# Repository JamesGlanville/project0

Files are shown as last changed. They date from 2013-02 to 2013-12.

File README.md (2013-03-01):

project0
========

My simple code for a launchpad VFD clock. Read the code for details, but the basic idea is:

On first power-up, the time is read via i2c from a DS1307 RTC chip.
One input is connected to the square wave 1Hz output of the DS1307, and increments the second counter on an interrupt.
One output is PWM'ed to drive a switch mode power supply that boosts 5v-50V for the tubes.
Three outputs send data to the MAX6921 driver chip constantly to keep the persistence of vision effect working.

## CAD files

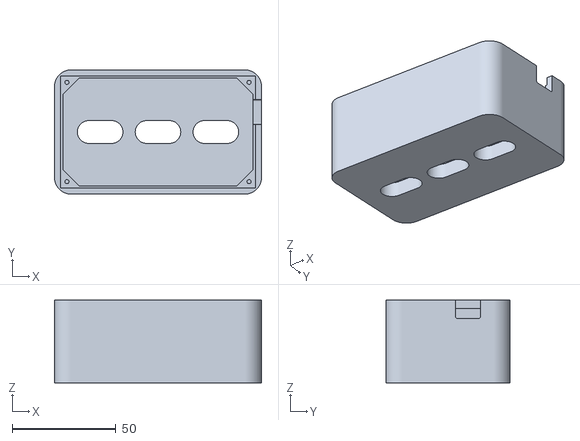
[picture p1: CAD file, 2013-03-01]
tube clock_fixed.stl
100.0 x 60.0 x 40.0

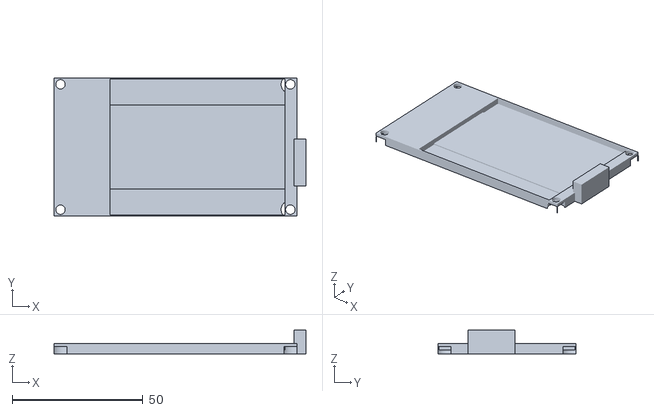
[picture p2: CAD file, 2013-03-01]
baselid.stl
96.5 x 53.0 x 9.00

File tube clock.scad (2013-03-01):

length=100;
width=60;
height=40;//35
cornerrad=8;
tubedia=11;
tubeseparation=27.94;//distance between center of tube clusters.
wallthickness=4;
screwx=length/2-1.5*wallthickness;
screwy=width/2-1.5*wallthickness;
screwrad=1;
lpy=52;
lpx=67;
//cube(24);
//88   52           30

$fn=100;

use <MCAD/boxes.scad>
use <MCAD/triangles.scad>
module body(){
mirror([0,0,1]){
difference()
{
translate([0,0,height/2])roundedBox([length,width,height],cornerrad,true);

difference(){
translate([0,0,height/2-7.5])roundedBox([length-wallthickness*2,width-wallthickness*2,height],0,true);

for (a=[1,-1]){
for (b=[1,-1]){
translate([a*length/1.6,b*width/2,height/2-wallthickness])rotate([0,0,45])cube(height,center=true);

}}}

for (c=[-1:1]){
translate([c*tubeseparation,0,0])roundedBox([tubedia*2,tubedia,100],tubedia/2,true);}


//roundedBox([length-wallthickness*1.5,width-wallthickness*1.5,1],0,true);
for (d=[1,-1]){
for (e=[1,-1]){
translate([d*screwx,e*screwy,-1])cylinder(r=screwrad,h=height-5);
}}
cube([length-wallthickness*1.5,width-1.5*wallthickness,wallthickness*2],center=true);
translate([50,9.68,2.49])roundedBox([100,12,13],1,false);
//cube([200,3,9]);
}}}

//translate([0,50,0]){
mirror([0,0,1])
difference(){

union(){
cube([length-wallthickness*1.5-1,width-1.5*wallthickness-1,wallthickness],center=true);
translate([length/2-wallthickness*0.75-1.5,-30/2,-7])cube([4.5,18,9]);



}
translate([-25,-lpy/2,-4])cube([lpx,lpy,4]);
translate([-25,-lpy/2,-3.5])cube([lpx,10,4]);
mirror([0,1,0])translate([-25,-lpy/2,-3.5])cube([lpx,10,4]);
/*translate([0,0,0.2])cylinder(r=10.5,h=10);
translate([27,0,0.2])cylinder(r=10.5,h=10);
translate([-27,0,0.2])cylinder(r=10.5,h=10);
translate([13.5,16,0.2])cylinder(r=10.5,h=10);
translate([13.5,-16,0.2])cylinder(r=10.5,h=10);
translate([-13.5,16,0.2])cylinder(r=10.5,h=10);
translate([-13.5,-16,0.2])cylinder(r=10.5,h=10);*/
for (d=[1,-1]){
for (e=[1,-1]){
translate([d*screwx,e*screwy,-5])cylinder(r=1.8,h=height-5);
translate([d*screwx,e*screwy,-0.7])cylinder(r=3.53,h=height-5);
}}
}

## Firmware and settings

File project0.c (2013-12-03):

#include "inc/hw_types.h"
#include "inc/hw_memmap.h"
#include "inc/hw_ints.h"
#include "inc/hw_gpio.h"
#include "inc/hw_timer.h"
#include "driverlib/sysctl.h"
#include "driverlib/gpio.h"
#include "driverlib/interrupt.h"
#include "driverlib/pwm.h"
#include "driverlib/timer.h"
#include "driverlib/pin_map.h"
#include "inc/lm4f120h5qr.h"
#include <stdint.h>
#include "softPwm.h" //From here: https://github.com/arcadien/pwm_test_stellpad1/tree/master/lab_project
#include "I2C_Stellaris_API.h" //From here: http://e2e.ti.com/support/microcontrollers/stellaris_arm/f/471/t/235926.aspx

#define DIN GPIO_PIN_1	//These are all on port F.
#define CLK GPIO_PIN_2	//They correspond to the 3 control wires going to the MAX6921.
#define LOAD GPIO_PIN_3

#define SECONDPULSE GPIO_PIN_6	//Port C. SECONDPULSE is connected to the 1Hz SQW output of the ds1307
#define SMPS_PWM GPIO_PIN_2		//Port B. This pin is connected to the SMPS mosfet gate for switching.

#define dutyCycle 40	//This is trial and error open-loop control - hacky but works well.
#define DS1307ADDRESS 0x68 //The i2c slave address of the DS1307
#define HAD_LENGTH	19

#define H1 0 //The time to set, with the time being H1,H2:M1,M2:S1,S2 so this time is 23:02:00
#define H2 1
#define M1 0
#define M2 8
#define S1 0
#define S2 0
//#define SETTIME //Comment this line out when you have set the time once.

//   Time-setting procedure:
// - Set the correct values in H1,H2....,S2 for a time a couple of minutes in the future.
// - Uncomment SETTIME and compile.
// - Upload the compiled program to the launchpad.
// - Press reset when the current time is what you set it to.
// - WITHOUT REMOVING POWER, comment out the SETTIME define, recompile, and upload.
// - The clock should now keep time on its own, just repeat this process when the clocks change.

void send_VFD(int digit, int number);
void rest();
void update_VFD();

unsigned long grid[6]={1<<0,1<<3,1<<9,1<<2,1<<13,1<<1};				//0'th digit, 1st digit... etc
unsigned long segments[10]={1<<11|1<<17|1<<6|1<<4|1<<19|1<<10,		//0		There might be a nicer way to do this, this works.
							1<<4|1<<10,								//1		This depends on how you have wired up your VFD
							1<<11|1<<4|1<<6|1<<4|1<<7|1<<19,		//2
							1<<11|1<<4|1<<6|1<<4|1<<7|1<<10,		//3
							1<<17|1<<4|1<<7|1<<10,					//4
							1<<11|1<<17|1<<6|1<<7|1<<10,			//5
							1<<11|1<<17|1<<7|1<<19|1<<10,			//6
							1<<4|1<<6|1<<10,						//7
							1<<11|1<<17|1<<4|1<<6|1<<7|1<<19|1<<10,	//8
							1<<4|1<<6|1<<7|1<<10|1<<17};			//9

unsigned long segments_hackaday[HAD_LENGTH]={	1<<4|1<<10|1<<17|1<<19|1<<7, //H
										1<<17|1<<19|1<<7|1<<11, //t
										1<<17|1<<19|1<<7|1<<11, //t
										1<<17|1<<19|1<<6|1<<7|1<<4, //P
										1<<6|1<<11, //:
										1<<19|1<<7|1<<4, // /
										1<<19|1<<7|1<<4, // /
										1<<4|1<<10|1<<17|1<<19|1<<7, //H
										1<<17|1<<4|1<<6|1<<7|1<<19|1<<10, //A
										1<<6|1<<17|1<<19|1<<11, //C
										1<<17|1<<6|1<<7|1<<19|1<<10, //k
										1<<17|1<<4|1<<6|1<<7|1<<19|1<<10, //A
										1<<7|1<<19|1<<11|1<<10|1<<4, //d
										1<<17|1<<4|1<<6|1<<7|1<<19|1<<10, //A
										1<<11|1<<17|1<<4|1<<7|1<<10, //y
										1<<11, //_
										1<<6|1<<17|1<<19|1<<11, //C
										1<<11|1<<17|1<<6|1<<4|1<<19|1<<10, //O
										1<<11|1<<17|1<<6|1<<7|1<<19 //M sideways
};

volatile int hour; //These must all be marked volatile as the NewSecond interrupt will use them.
volatile int minute;
volatile int second;

volatile int numbers[6];

void update_VFD()
{
	int i;
	for (i = 0; i < 6; i ++)
	{
		send_VFD(i, numbers[i]);
	}

}

void update_HAD()
{
	int i;
	int j;
	while(1)
	{
		for (i=0;i<=13;i++)
		{
			for(j=0;j<6000;j++)
			{
				send_VFD(j%6,10+i+j%6);
			}
		}
		for (i=13;i>=0;i--)
		{
			for(j=0;j<6000;j++)
			{
				send_VFD(j%6,10+i+j%6);
			}
		}
	}
}

void getDS1307time()
{
	unsigned long temp;
	I2CSetup(I2C2_MASTER_BASE, false); //Port E: pin 4 is SCL, pin 5 is SDA. The false value sets the speed to 100kHz (I think)
#ifdef SETTIME
	SysCtlDelay(1000);
	I2CRegWrite(I2C2_MASTER_BASE, DS1307ADDRESS, 0, (S1<<4)|S2); //set seconds - push the first digit left 4 bits into bits 6,5,4 (see datasheet), then OR with S2 which is already in the right place bit-wise.
	I2CRegWrite(I2C2_MASTER_BASE, DS1307ADDRESS, 1, (M1<<4)|M2); //set minutes
	I2CRegWrite(I2C2_MASTER_BASE, DS1307ADDRESS, 2, (H1<<4)|H2); //set 24 hour bit and hours
	//Don't bother setting days/months/years - should be easy to work out what to do from the datasheet.
	I2CRegWrite(I2C2_MASTER_BASE, DS1307ADDRESS, 7, 0x90); //sets up SQW output at 1Hz 0x90 = 10010000. The first bit (bit 7) is actually unneeded. The 4th (bit 4) turns on the SQW output.
#endif
	temp = I2CRegRead(I2C2_MASTER_BASE, DS1307ADDRESS, 0);
	second = (temp&0x0F)+10*((temp>>4)&0x07); //Messy bit manipulations to extract the seconds. 0x0F = 00001111, so OR'ing the temp value with it gives you only the last four bits.
	temp = I2CRegRead(I2C2_MASTER_BASE, DS1307ADDRESS, 1);
	minute = (temp&0x0F)+10*((temp>>4)&0x07);
	temp = I2CRegRead(I2C2_MASTER_BASE, DS1307ADDRESS, 2);
	hour = (temp&0x0F)+10*((temp>>4)&0x03);

	numbers[0]=hour/10;
	numbers[1]=hour%10;
	numbers[2]=minute/10;
	numbers[3]=minute%10;
	numbers[4]=second/10;
	numbers[5]=second%10;
}

void NewSecond()
{
	GPIOPinIntClear(GPIO_PORTC_BASE,SECONDPULSE); //Clears interrupt.

	second++;
	if (second	== 60){second	= 0; minute++;	} //Simple code to get the time to work correctly.
	if (minute	== 60){minute	= 0; hour++;	}
	if (hour	== 24){hour		= 0;			}
	numbers[0]=hour/10; //numbers[] is an integer array, and the calculations are always rounded down so this works.
	numbers[1]=hour%10;
	numbers[2]=minute/10;
	numbers[3]=minute%10;
	numbers[4]=second/10;
	numbers[5]=second%10;
}

void send_VFD(int digit, int number) //numbers 10->29 are http://hackaday.com
{
	long data=0; //This will become the blob of data that is pushed to the MAX6921
	int i;
	data |= grid[digit];		//the grid bit is OR'ed to add it to data.
	if(number<10)
	{
		data |= segments[number];	//Likewise with the segments.
	}
	else
	{
		data |= segments_hackaday[number-10];
	}
	rest(); //pause for a bit
	GPIO_PORTF_DATA_R &= ~LOAD; //Pulls LOAD low. This should really use a higher level function for neatness.
	rest();
	GPIO_PORTF_DATA_R =0; //Pulls the whole of port F low (why?!?)
	rest();
	for (i = 0; i<20;i++)
	{
		GPIO_PORTF_DATA_R &= ~CLK; //Pulls CLK low.
		rest();
		if (data & (1 << i)) {		GPIO_PORTF_DATA_R |= DIN; } //If needed, DIN goes HIGH.
		else {GPIO_PORTF_DATA_R &= ~DIN;}						//Otherwise, DIN goes LOW.
		rest();
		GPIO_PORTF_DATA_R |= CLK; //Pulls CLK high.
		rest();
	}
	rest(); //Not sure why I need more than 1 here.
	rest();
	rest();
	rest();
	GPIO_PORTF_DATA_R |=LOAD; //LOAD goes high.
}

void rest()
{
    SysCtlDelay(20); //This is the delay to give the MAX6921 time to react to data. It may not be needed.

}

int
main(void)
{
    // Setup the system clock to run at 50 Mhz from PLL with crystal reference
    //
    SysCtlClockSet(SYSCTL_SYSDIV_4|SYSCTL_USE_PLL|SYSCTL_XTAL_16MHZ|
                    SYSCTL_OSC_MAIN);
	SysCtlPeripheralEnable(SYSCTL_PERIPH_GPIOB); //Enables the GPIO ports needed.
	SysCtlPeripheralEnable(SYSCTL_PERIPH_GPIOF);
	SysCtlPeripheralEnable(SYSCTL_PERIPH_GPIOC);

	GPIOPinTypeGPIOOutput(GPIO_PORTB_BASE, SMPS_PWM); //Sets the various pins to be inputs or outputs.
	GPIOPinTypeGPIOOutput(GPIO_PORTF_BASE, DIN | LOAD | CLK);
	GPIOPinTypeGPIOInput(GPIO_PORTC_BASE,SECONDPULSE);

    getDS1307time(); //Grab the current time, before interrupts start.

	GPIOPinIntClear(GPIO_PORTC_BASE,0xFF); //Clear all interrupts from port C.
	GPIOPortIntRegister(GPIO_PORTC_BASE, &NewSecond); //Registers NewSecond() as the interrupt handler.
	GPIOPadConfigSet(GPIO_PORTC_BASE, SECONDPULSE, GPIO_STRENGTH_2MA,GPIO_PIN_TYPE_STD_WPU); //Enables a weak (2mA) pullup on the pin. This is needed as the SQW output is open-drain.
	GPIOIntTypeSet(GPIO_PORTC_BASE, SECONDPULSE, GPIO_FALLING_EDGE); //Sets the interrupt to trigger on a falling edge.
	GPIOPinIntEnable(GPIO_PORTC_BASE,SECONDPULSE); //Enables the interrupt.
	IntEnable(INT_GPIOC); //Enables the port interrupt.
    IntMasterEnable(); //Enables all interrupts.

	// clear any existing state
	GPIOPinWrite(GPIO_PORTB_BASE, SMPS_PWM, 0); //Don't think this matters much since it's about to start PWM'ing.

	softPwmInit(); //Sets up the pwm (see softPwm.c)

	unsigned long base_freq = 6000; // 6kHz pwm. I have no idea why, but higher frequencies resulted in a lower output voltage, which makes no sense.

    softPwmConfig(GPIO_PORTB_BASE, SMPS_PWM, base_freq, dutyCycle); //Starts the SMPS PWM.

    if(second==37)
    {
    	update_HAD();
    }

    while(1)
    {
    	update_VFD(); //Keep updating the VFD. interrupts will manage the changing time.
    }
}

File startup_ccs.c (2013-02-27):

//*****************************************************************************
//
// startup_ccs.c - Startup code for use with TI's Code Composer Studio.
//
// Copyright (c) 2012 Texas Instruments Incorporated.  All rights reserved.
// Software License Agreement
// 
// Texas Instruments (TI) is supplying this software for use solely and
// exclusively on TI's microcontroller products. The software is owned by
// TI and/or its suppliers, and is protected under applicable copyright
// laws. You may not combine this software with "viral" open-source
// software in order to form a larger program.
// 
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
// This is part of revision 9453 of the EK-LM4F120XL Firmware Package.
//
//*****************************************************************************

//*****************************************************************************
//
// Forward declaration of the default fault handlers.
//
//*****************************************************************************
void ResetISR(void);
static void NmiSR(void);
static void FaultISR(void);
static void IntDefaultHandler(void);

//*****************************************************************************
//
// External declaration for the reset handler that is to be called when the
// processor is started
//
//*****************************************************************************
extern void _c_int00(void);

extern void Timer0IntHandler();
extern void NewSecond();

//*****************************************************************************
//
// Linker variable that marks the top of the stack.
//
//*****************************************************************************
extern unsigned long __STACK_TOP;

//*****************************************************************************
//
// The vector table.  Note that the proper constructs must be placed on this to
// ensure that it ends up at physical address 0x0000.0000 or at the start of
// the program if located at a start address other than 0.
//
//*****************************************************************************
#pragma DATA_SECTION(g_pfnVectors, ".intvecs")
void (* const g_pfnVectors[])(void) =
{
    (void (*)(void))((unsigned long)&__STACK_TOP),
                                            // The initial stack pointer
    ResetISR,                               // The reset handler
    NmiSR,                                  // The NMI handler
    FaultISR,                               // The hard fault handler
    IntDefaultHandler,                      // The MPU fault handler
    IntDefaultHandler,                      // The bus fault handler
    IntDefaultHandler,                      // The usage fault handler
    0,                                      // Reserved
    0,                                      // Reserved
    0,                                      // Reserved
    0,                                      // Reserved
    IntDefaultHandler,                      // SVCall handler
    IntDefaultHandler,                      // Debug monitor handler
    0,                                      // Reserved
    IntDefaultHandler,                      // The PendSV handler
    IntDefaultHandler,                      // The SysTick handler
    IntDefaultHandler,                      // GPIO Port A
    IntDefaultHandler,                      // GPIO Port B
    IntDefaultHandler,                      // GPIO Port C
    IntDefaultHandler,                      // GPIO Port D
    IntDefaultHandler,                      // GPIO Port E
    IntDefaultHandler,                      // UART0 Rx and Tx
    IntDefaultHandler,                      // UART1 Rx and Tx
    IntDefaultHandler,                      // SSI0 Rx and Tx
    IntDefaultHandler,                      // I2C0 Master and Slave
    IntDefaultHandler,                      // PWM Fault
    IntDefaultHandler,                      // PWM Generator 0
    IntDefaultHandler,                      // PWM Generator 1
    IntDefaultHandler,                      // PWM Generator 2
    IntDefaultHandler,                      // Quadrature Encoder 0
    IntDefaultHandler,                      // ADC Sequence 0
    IntDefaultHandler,                      // ADC Sequence 1
    IntDefaultHandler,                      // ADC Sequence 2
    IntDefaultHandler,                      // ADC Sequence 3
    IntDefaultHandler,                      // Watchdog timer
//    IntDefaultHandler,                      // Timer 0 subtimer A
    Timer0IntHandler,                      // Timer 0 subtimer A
    IntDefaultHandler,                      // Timer 0 subtimer B
    IntDefaultHandler,                      // Timer 1 subtimer A
    IntDefaultHandler,                      // Timer 1 subtimer B
    IntDefaultHandler,                      // Timer 2 subtimer A
    IntDefaultHandler,                      // Timer 2 subtimer B
    IntDefaultHandler,                      // Analog Comparator 0
    IntDefaultHandler,                      // Analog Comparator 1
    IntDefaultHandler,                      // Analog Comparator 2
    IntDefaultHandler,                      // System Control (PLL, OSC, BO)
    IntDefaultHandler,                      // FLASH Control
    IntDefaultHandler,                      // GPIO Port F
    IntDefaultHandler,                      // GPIO Port G
    IntDefaultHandler,                      // GPIO Port H
    IntDefaultHandler,                      // UART2 Rx and Tx
    IntDefaultHandler,                      // SSI1 Rx and Tx
    IntDefaultHandler,                      // Timer 3 subtimer A
    IntDefaultHandler,                      // Timer 3 subtimer B
    IntDefaultHandler,                      // I2C1 Master and Slave
    IntDefaultHandler,                      // Quadrature Encoder 1
    IntDefaultHandler,                      // CAN0
    IntDefaultHandler,                      // CAN1
    IntDefaultHandler,                      // CAN2
    IntDefaultHandler,                      // Ethernet
    IntDefaultHandler,                      // Hibernate
    IntDefaultHandler,                      // USB0
    IntDefaultHandler,                      // PWM Generator 3
    IntDefaultHandler,                      // uDMA Software Transfer
    IntDefaultHandler,                      // uDMA Error
    IntDefaultHandler,                      // ADC1 Sequence 0
    IntDefaultHandler,                      // ADC1 Sequence 1
    IntDefaultHandler,                      // ADC1 Sequence 2
    IntDefaultHandler,                      // ADC1 Sequence 3
    IntDefaultHandler,                      // I2S0
    IntDefaultHandler,                      // External Bus Interface 0
    IntDefaultHandler,                      // GPIO Port J
    IntDefaultHandler,                      // GPIO Port K
    IntDefaultHandler,                      // GPIO Port L
    IntDefaultHandler,                      // SSI2 Rx and Tx
    IntDefaultHandler,                      // SSI3 Rx and Tx
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

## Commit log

2013-02-27 Hopefully done, but i2c comms not tested at all.
2013-03-01 Added stl/scad files.
    [baselid.stl, tube clock.scad, tube clock_fixed.stl]
2013-12-03 started adding HAD easter egg
    [baselid.stl, tube clock.scad, tube clock_fixed.stl]
